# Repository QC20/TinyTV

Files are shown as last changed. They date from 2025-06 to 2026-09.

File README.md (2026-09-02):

# TinyTV

A small 3D-printed television with a Raspberry Pi inside. It plays a library of
episodes and old commercials on a loop — no menu, no remote, no interface. You
flip the switch on the side and something is on, the way a TV in the corner of a
room used to work.

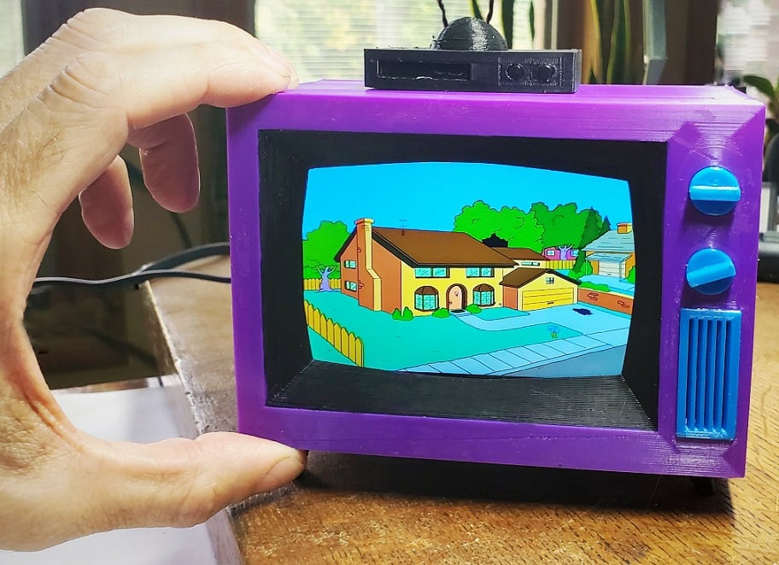
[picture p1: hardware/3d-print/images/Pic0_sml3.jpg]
The printed enclosure


*Enclosure model and photo by [highping on Thingiverse](https://www.thingiverse.com/thing:5019648), used under CC BY.*

The Pi boots straight into a video player. There is no desktop and nothing to log
into. Episodes are shuffled, and after each one a commercial plays before the
next episode starts — which is most of what makes it feel like television rather
than a video player in a box.

## How it works

Everything is pre-processed on a desktop machine, so the Pi only ever has to do
the easy job of playing files. Videos are encoded down to roughly 780×480 and
rotated to match the panel, black bars cropped, subtitles burned in if there are
any. That happens once, in [code/encoding](code/encoding).

On the Pi, [player.py](code/player/player.py) shuffles the contents of
`videos/tv` and `videos/commercials`, then alternates between them forever. It
plays through `mpv` on the DRM video output, which draws directly to HDMI with no
X server running. Before each file it probes the codec with `ffprobe` and picks
its decoder flags accordingly: H.264 goes to the Pi's hardware decoder, anything
else (H.265, VP9, AV1) falls back to software with the loop filter switched off,
because a Pi 3B has no hardware path for those and will otherwise drop most of
the frames.

Play counts are written to `playback_state.txt` next to the script — a plain text
file you can open and read, on purpose.

[buttons.py](code/player/buttons.py) watches a toggle switch on GPIO 26. When
it's off, GPIO 18 goes low to kill the backlight and GPIO 19 is dropped back to
an input, which cuts the PWM audio feeding the amp. Screen and sound go together,
so the switch on the side of the case behaves like a real power switch.

## Hardware

| Part | Notes |
| --- | --- |
| Raspberry Pi 3B | The player is tuned for its decoder; a newer Pi has more headroom |
| Waveshare 4″ HDMI LCD | 800×480 IPS, resistive touch (unused here), HDMI + USB |
| Waveshare UPS HAT (D) | 2× 5300 mAh cells, INA219 current sensor on I²C `0x43` |
| Adafruit MAX98357 | Class-D mono amp driving a small speaker |
| Toggle switch, 1 kΩ pot, relay | Power and volume on the front panel |

Wiring diagram (again from the original build):
[hardware/3d-print/images/Wiring.jpg](hardware/3d-print/images/Wiring.jpg).
Datasheets for the HAT and the amp are in [hardware/datasheets](hardware/datasheets).

## Layout

```text
boot/          Files that go on the SD card's boot partition before first boot
code/
  player/      What runs on the Pi: playback loop and the power switch handler
  encoding/    Desktop-side ffmpeg tooling that prepares videos for the screen
  monitoring/  Battery, temperature and system telemetry over the INA219
  video-analysis/  Library statistics — how many hours of content is on there
  experiments/ Parked attempts, kept for reference
docs/          Display setup guide and the playback design notes
hardware/      STLs, Fusion 360 source, renders and component datasheets
samples/       An example encoded clip
```

## Getting one running

1. Flash Raspberry Pi OS Lite and set the Pi up headless. The display needs a
   custom HDMI mode and a device tree overlay before it will show anything —
   [docs/pi-display-setup.md](docs/pi-display-setup.md) has the exact
   `config.txt` lines and the touchscreen overlay.
2. Copy the contents of [boot/](boot/) to the boot partition. Fill in your own
   SSID and password in `wpa_supplicant.conf` first.
3. Install the runtime dependencies on the Pi:
   ```bash
   sudo apt install mpv ffmpeg python3-rpi.gpio
   pip3 install pi-ina219 psutil
   ```
4. Encode your videos with [code/encoding/480x800-screen.py](code/encoding/480x800-screen.py)
   and copy them to `code/player/videos/tv` and `code/player/videos/commercials`.
5. Run `python3 player.py`. Once it looks right, put it behind a systemd unit so
   it comes up on boot.

## Known gaps

This is a finished object rather than a finished piece of software, and a few
things never got past "good enough":

- **Playback state only saves on a clean exit.** `player.py` writes
  `playback_state.txt` when you Ctrl+C it. Pull the power — which is how the
  thing is normally switched off — and the session's play counts are lost.
- **The rotation is a shuffle, not the design in the notes.**
  [docs/playback-design.md](docs/playback-design.md) describes a session system
  that picks randomly from what hasn't played yet, survives restarts, and picks
  up new files automatically. `code/experiments/player_WITH-CIRCULATION.py`
  implements it, but it plays through `--hwdec=auto` and stutters badly on a
  3B, so the simpler shuffle is what actually ships.
- **The VCR buttons aren't wired to anything.** The case models two micro
  switches into the VCR on top. Skip and rewind would be the obvious use.
- **No service file.** Starting on boot is left to you.

## Credits

The enclosure is [The Simpsons TV (Remixed for HDMI display)](https://www.thingiverse.com/thing:5019648)
by **highping**, itself a remodel of [buba447's original](https://www.thingiverse.com/thing:4943159).
buba447's [build guide](https://withrow.io/simpsons-tv-build-guide) still covers
most of the hardware side; the display setup is the part that differs.

## License

The code in this repository is MIT licensed — see [LICENSE](LICENSE).

The 3D models in [hardware/3d-print](hardware/3d-print) are not mine and are not
covered by that. They are Creative Commons Attribution, by highping — see
[hardware/3d-print/LICENSE.txt](hardware/3d-print/LICENSE.txt).

Bring your own video. Nothing here ships with content, and the point is to play
things you already own.

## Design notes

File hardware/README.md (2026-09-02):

# Hardware

**`3d-print/`** — the enclosure. STLs in `stl/`, the Fusion 360 source as
`Simpsons_TV.f3d`, and renders and build photos in `images/`. `THINGIVERSE.txt`
is the original author's description, including print orientations and the
wiring notes worth reading before you start.

Print the front face down (the grill is a separate part so it needs no support).
The VCR and the volume knob are the only pieces that want support.

This is not my model — it's [The Simpsons TV (Remixed for HDMI display)](https://www.thingiverse.com/thing:5019648)
by highping, CC BY. See `LICENSE.txt`.

**`datasheets/`** — vendor documentation for the two boards that needed it:
the Waveshare UPS HAT (D) and the Adafruit MAX98357 I²S amp.

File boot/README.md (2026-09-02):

# Boot partition files

Copy these to the root of the SD card's `boot` partition before the Pi's first
boot. They are read once at startup and then ignored.

| File | Purpose |
| --- | --- |
| `wpa_supplicant.conf` | Wi-Fi credentials. **Fill in your own SSID and password** — the committed values are placeholders. |
| `ssh` | Empty file. Its presence enables the SSH server on first boot. |
| `waveshare-ads7846.dtbo` | Device tree overlay for the display's ADS7846 resistive touch controller. This one goes in `/boot/overlays/`, not the root. |

`config.txt` also needs the HDMI mode for the 800×480 panel — those lines are in
[../docs/pi-display-setup.md](../docs/pi-display-setup.md).

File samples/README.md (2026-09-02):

# Samples

`480x320.mp4` is an encoded clip, kept as a reference for what the converter
output looks like — resolution, bitrate and how it sits on the panel.

It is 480×320, from an earlier build that used a smaller screen. The current
target is 780×480; see [../code/encoding](../code/encoding).

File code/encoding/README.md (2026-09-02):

# Encoding videos for the screen

The Pi is not fast enough to scale and decode arbitrary video in real time, so
everything gets converted once on a desktop machine and copied over ready to
play. These are the ffmpeg wrappers that do it.

`480x800-screen.py` is the one to use. The others are kept in `deprecated/`
because earlier builds used different panels.

## What it does

Per file, in this order:

1. **Crops black bars.** Samples the frame at 10%, 50% and 90% through the video
   and crops letterboxing when it exceeds 2% of the frame. Sampling at three
   points avoids being fooled by a dark opening shot.
2. **Picks target dimensions.** Height is fixed at 480. Width is allowed to land
   anywhere between 770 and 800, preferring 780 — the case covers a few pixels
   at the edges, so filling the panel exactly wastes them. It searches for the
   width that needs the least stretching, staying inside a 12% stretch / 20%
   squeeze limit.
3. **Burns in subtitles** if a `.srt` with the same base name sits next to the
   source. 18px Arial with a 2px outline, which is about the smallest that stays
   readable on a 4″ panel.
4. **Rotates 90°** if `ROTATE` is on, subtitles along with it.
5. **Encodes** to H.264 Main / Level 3.0, CRF 23, `veryslow`, AAC audio at
   256 kbps, `yuv420p`, faststart.

Existing outputs are skipped, and sources are never modified.

## Requirements

ffmpeg on PATH, and Python 3.

```bash
sudo apt install ffmpeg    # Debian/Raspberry Pi OS
brew install ffmpeg        # macOS
```

## Use

Put your videos in an `input/` folder beside the script; `output/` is created
for you.

```text
code/encoding/
├── 480x800-screen.py
├── input/     <- source videos (and matching .srt files, if any)
└── output/    <- converted files land here
```

```bash
python3 480x800-screen.py
```

Progress looks like this:

```text
(1/10)
Analyzing 'sample_video'...
  Original dimensions: 1920x1080
  Duration: 00:05:23
  Found subtitle file: sample_video.srt
  Detecting black bars (sampling 10s)...
  Black bars detected! Original: 1920x1080, After crop: 1920x800
  Optimal target dimensions: 780x480
  Applying rotation: counterclockwise
Encoding 'sample_video' with filters: crop=1920:800:0:140,scale=780:480,...
  Progress: [====================] 100.00% (00:05:23 / 00:05:23)
 -> Done in 142.3s, size=8472 KB
```

Roughly 6–8 minutes per 30-minute episode on a modern laptop, scaling with how
many threads you give it.

## Settings

All near the top of the script:

```python
TARGET_HEIGHT = 480
TARGET_WIDTH_PREFERRED = 780
TARGET_WIDTH_MIN = 770
TARGET_WIDTH_MAX = 800

ROTATE = True
ROTATE_DIR = 'counterclockwise'

MAX_STRETCH = 1.12          # how much distortion to tolerate
MIN_SQUEEZE = 0.80

SUBTITLE_FONT_SIZE = 18
SUBTITLE_FONT_NAME = 'Arial'
SUBTITLE_OUTLINE = 2

MAX_CPU_THREADS = multiprocessing.cpu_count() // 2
```

Worth knowing:

- **Video looks stretched** — tighten `MAX_STRETCH` and `MIN_SQUEEZE` towards 1.0.
- **Too slow** — raise `MAX_CPU_THREADS`, or change the preset from `veryslow`
  to `medium`. `veryslow` buys maybe 5% file size for several times the wait.
- **Rotated the wrong way** — flip `ROTATE_DIR`.
- **Quality** — CRF 18 is close to lossless and much larger, 23 is the default,
  26 is noticeably softer but small. On a 4″ screen 26 is more defensible than
  it sounds.

## The deprecated scripts

| Script | Target |
| --- | --- |
| `TinyTV_Converter.py` | Same as `480x800-screen.py`, but reads from `~/Desktop/c_input` instead of a folder beside the script |
| `video-converter_800x480.py` | Aspect-preserving 480p for a normal monitor |
| `video-converter_480x320.py` | Fixed 480×320 with letterboxing, for 2.8″–3.5″ panels |
| `800x480_Resolution.py` | Earlier pass at the 800×480 conversion |

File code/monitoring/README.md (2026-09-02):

# Monitoring

Diagnostics for the UPS HAT, run over SSH. None of this is needed for playback.

| Script | What it shows |
| --- | --- |
| `battery-monitor.py` | One reading: voltage, current, power, shunt voltage |
| `battery_watch.py` | The same on a 3-second loop, plus charge state and a runtime estimate |
| `status.py` | Full dashboard — battery, CPU load and temperature, GPU clock, RAM, disk, network throughput, top processes, and firmware throttle flags |

All three talk to the INA219 on the UPS HAT at I²C address `0x43`, with a 0.1 Ω
shunt. Capacity is hardcoded to 10600 mAh (2× 5300 mAh); change
`BATTERY_CAPACITY_MAH` if your pack differs.

Battery percentage is interpolated from voltage between 3.0 V and 4.2 V. That's
a rough approximation — lithium cells sit near 3.7 V for most of their discharge,
so the middle of the range reads low and the number moves in jumps.

```bash
pip3 install pi-ina219 psutil
python3 status.py
```

I²C needs to be enabled (`raspi-config` → Interface Options → I2C).

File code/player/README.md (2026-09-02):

# Player

What runs on the Pi.

**`player.py`** shuffles `videos/tv` and `videos/commercials` (both relative to
this file) and alternates between them: an episode, then a commercial, then the
next episode. Playback goes through `mpv --vo=drm` straight to HDMI, so no
desktop is needed.

Decoder flags are chosen per file after probing the codec with `ffprobe`. H.264
uses the Pi's hardware decoder; H.265, VP9 and AV1 fall back to four software
threads with the loop filter disabled, which is the difference between watchable
and a slideshow on a 3B. Encode to H.264 and none of this matters.

Play counts go to `playback_state.txt` next to the script, written on Ctrl+C.

```bash
mkdir -p videos/tv videos/commercials
# copy encoded files in, then
python3 player.py
```

**`buttons.py`** polls a toggle switch on GPIO 26 every 300 ms. On, it drives
GPIO 18 high for the backlight and puts GPIO 19 into ALT5 — its PWM audio
function — via `raspi-gpio`. Off, it reverses both, so screen and sound come up
and go down together.

If yours works backwards, invert the read; there's a comment in the loop marking
the line.

Needs `mpv`, `ffmpeg` and `RPi.GPIO`.

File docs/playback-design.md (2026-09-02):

# Playback rotation — design notes

What the video counter system was meant to do. This is the spec, not a
description of what ships; see [Known gaps](../README.md#known-gaps) for where
the two diverge.

## Session-based cycle

A *session* is one pass in which every video file plays exactly once. When
everything has played, a new session starts. Sessions repeat indefinitely.

## Random, but constrained

Pick randomly, but only from the videos that haven't played yet this session.
Straight random selection means an unlucky file can go months without coming up;
drawing without replacement spreads playtime evenly while keeping the order
unpredictable.

## State survives restarts

If the player stops, it resumes where it left off. Videos already played this
session stay marked as played, and the rest stay in the pool.

## History is kept

Track total plays per file across all sessions, not just the current one. A new
session resets the "played this session" flag but not the running count, so
"this one has been on 47 times" stays true.

## New files are picked up on their own

Anything dropped into the video directories is detected and joins the current
session as unplayed. Nothing to register by hand.

## The tracking file is readable

`playback_state.txt` is plain text so anyone can open it and see what has played,
what hasn't, and how often — no database, no JSON.

---

In short: fair rotation that remembers where it was, keeps its history, and
stays legible to someone who doesn't write code.

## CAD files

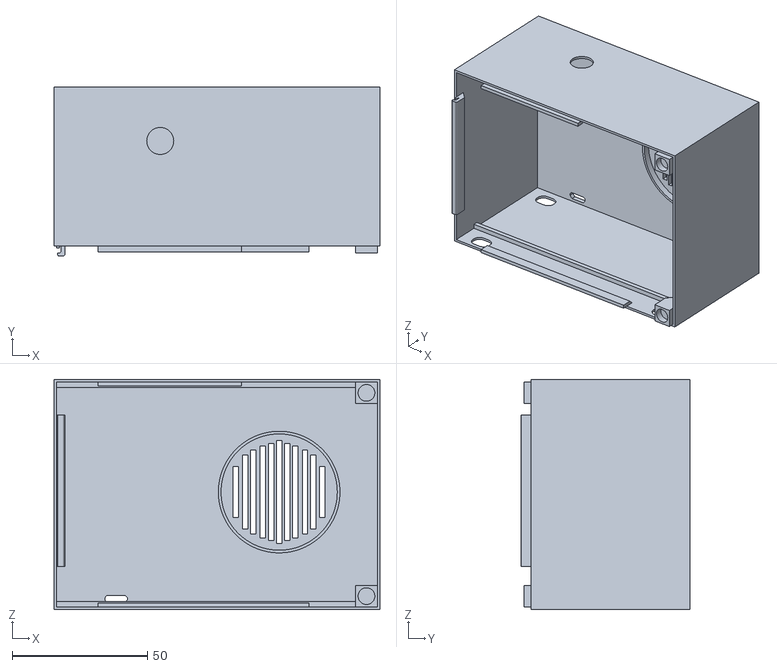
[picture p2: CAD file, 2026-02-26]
hardware/3d-print/stl/STV_Body.stl
120.6 x 62.6 x 85.2

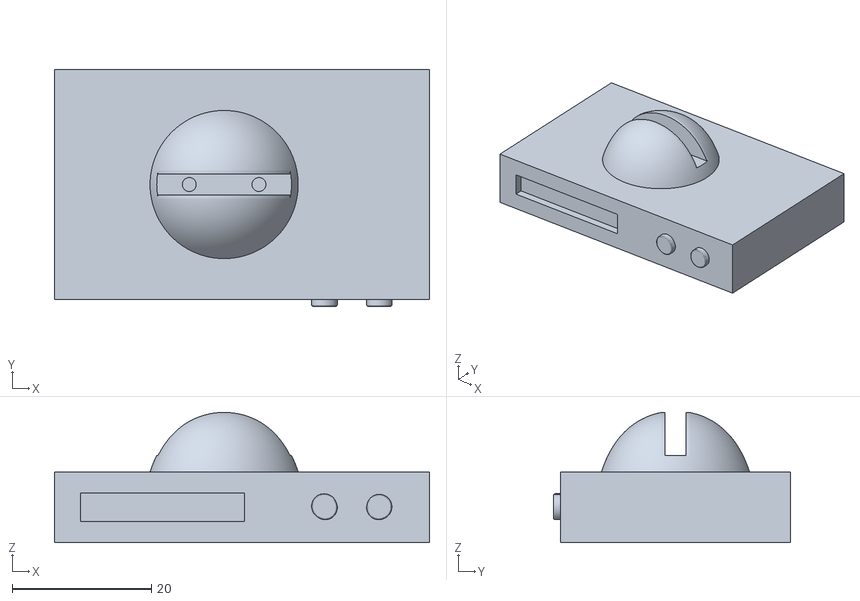
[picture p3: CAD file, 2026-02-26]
hardware/3d-print/stl/STVmod_VCR_solid_buttons.stl
53.8 x 34.0 x 18.7

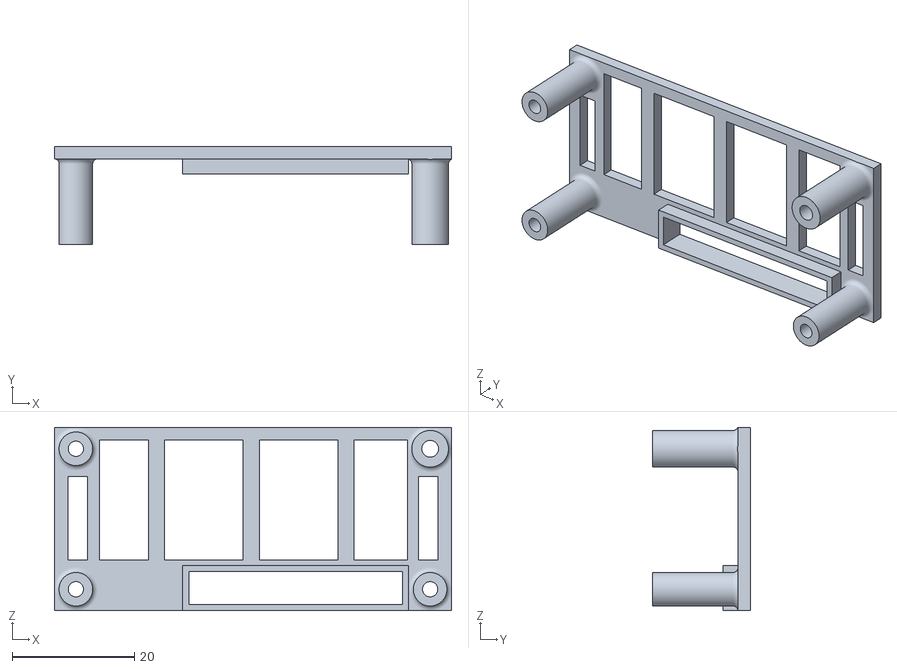
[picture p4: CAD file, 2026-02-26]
hardware/3d-print/stl/standoff.stl
65.0 x 16.0 x 30.0

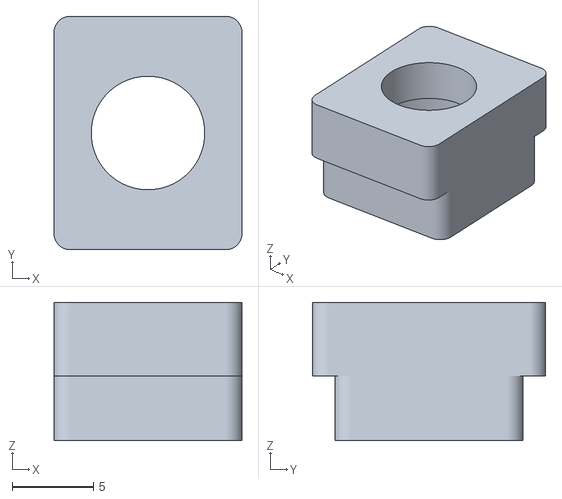
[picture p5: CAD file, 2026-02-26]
hardware/3d-print/stl/STV_Vknob_Base.stl
11.6 x 14.4 x 8.53

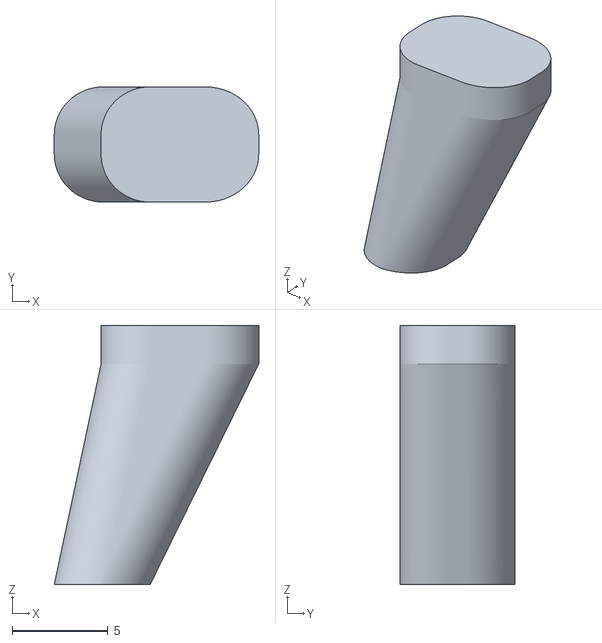
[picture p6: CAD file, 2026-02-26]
hardware/3d-print/stl/STV_Leg.stl
10.7 x 6.00 x 13.5

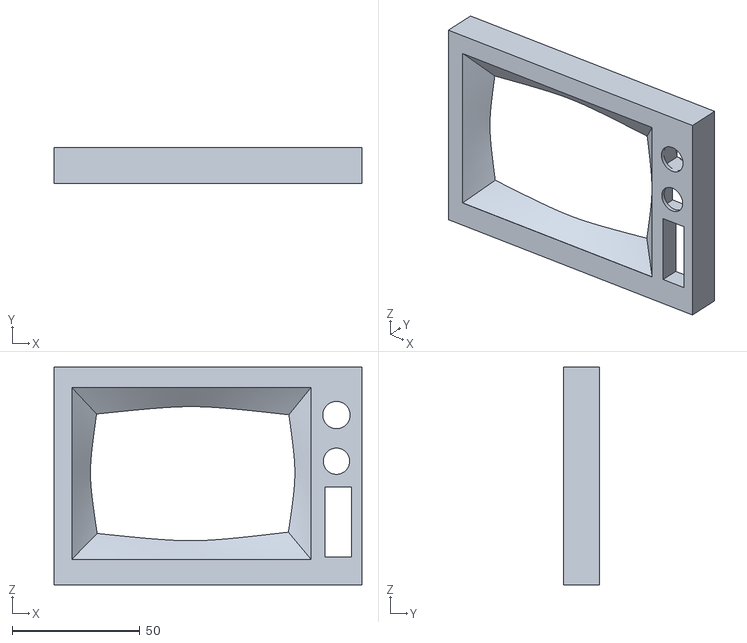
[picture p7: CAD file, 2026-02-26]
hardware/3d-print/stl/STV_Front.stl
120.6 x 14.0 x 85.2

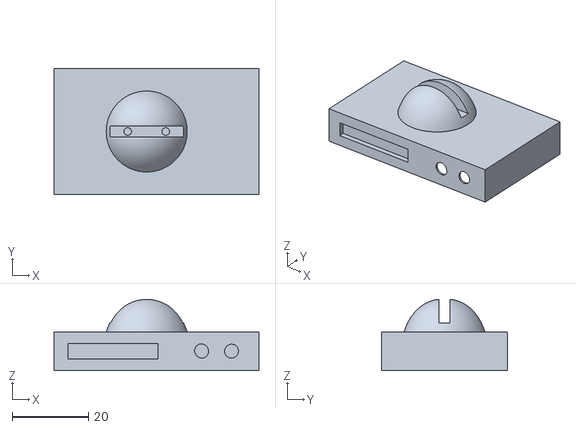
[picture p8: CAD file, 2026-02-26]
hardware/3d-print/stl/STV_VCR.stl
53.8 x 33.0 x 18.7

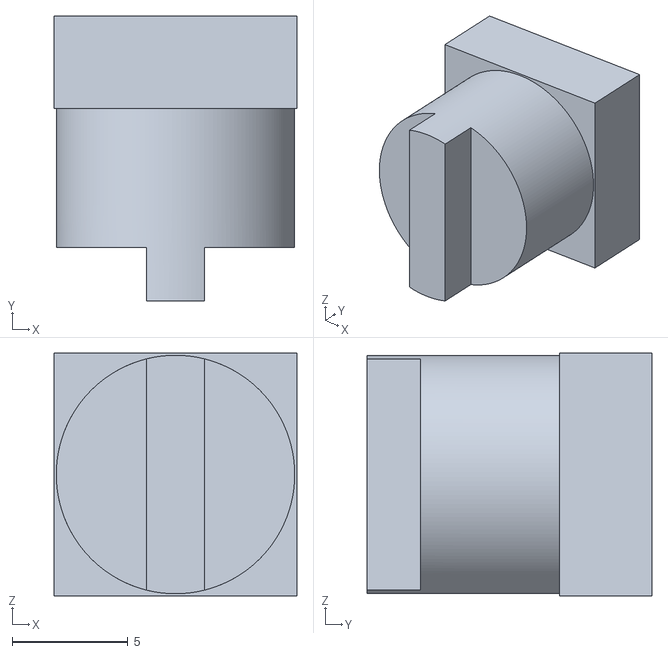
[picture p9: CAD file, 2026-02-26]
hardware/3d-print/stl/STV_Pknob.stl
10.5 x 12.3 x 10.5

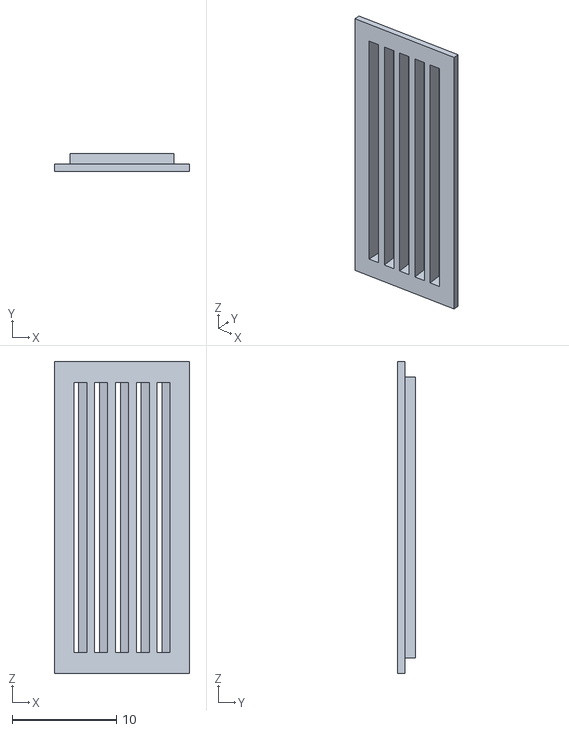
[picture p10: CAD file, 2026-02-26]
hardware/3d-print/stl/STV_Front_insert.stl
13.0 x 1.70 x 30.0

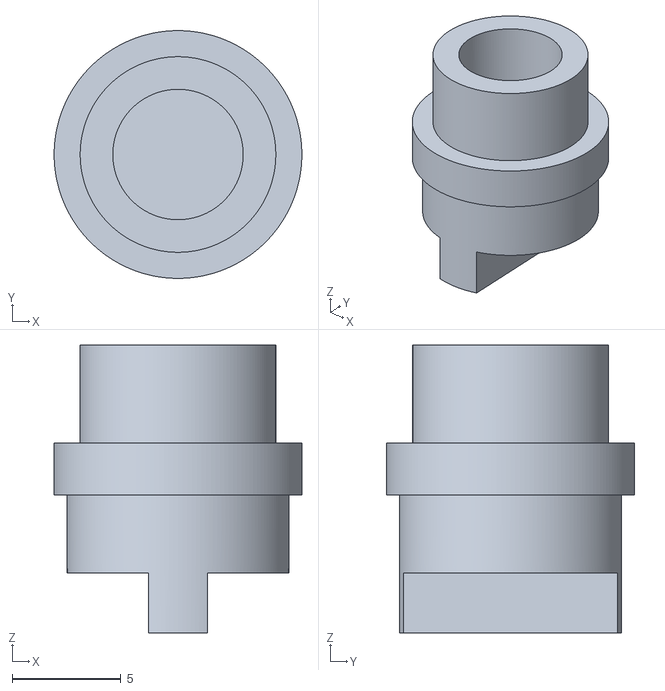
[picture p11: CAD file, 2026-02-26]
hardware/3d-print/stl/STV_VKnob.stl
11.4 x 11.4 x 13.2

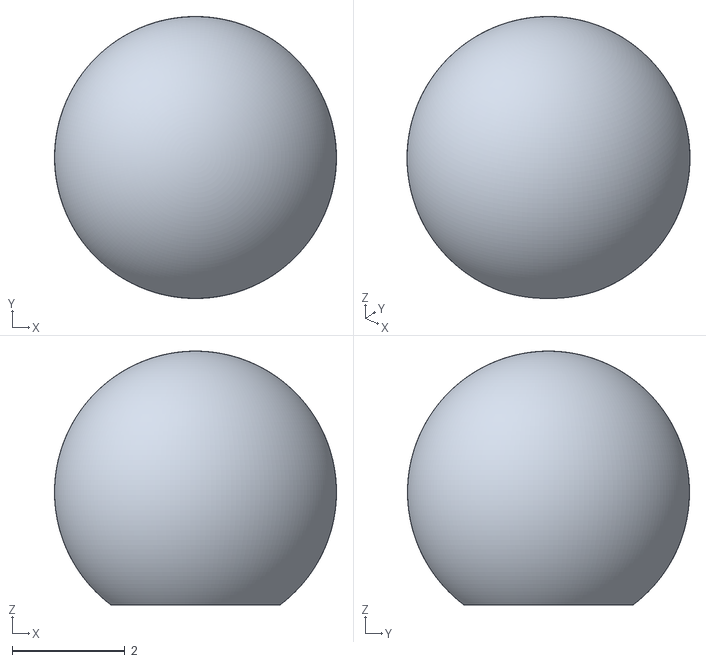
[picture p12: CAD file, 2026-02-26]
hardware/3d-print/stl/STV_AntennaTop.stl
5.00 x 5.00 x 4.50

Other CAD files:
hardware/3d-print/stl/STVmod_Body_no_hole_on_top.stl
hardware/3d-print/Simpsons_TV.f3d

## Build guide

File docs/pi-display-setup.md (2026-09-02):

# Setting up the Waveshare 4" HDMI LCD

Getting a Waveshare 4-inch HDMI LCD (800×480) working on a headless Raspberry
Pi: Wi-Fi and SSH, the HDMI mode the panel needs, and the touchscreen overlay.
The display will not show anything until `config.txt` is right, so this has to
happen before the Pi is any use.

Ready-made copies of the files mentioned here are in [../boot](../boot).

---

## Prerequisites

- **Raspberry Pi** (any model with HDMI output)
- **microSD card** (≥8 GB)
- **Waveshare 4″ HDMI LCD (800×480)**
- **micro USB power supply** (≥2 A recommended)
- **A computer** (Windows/macOS/Linux) with:
  - SD-card reader
  - Text editor (e.g., Sublime, VS Code, Notepad++)

---

## 1. Download & Flash Raspberry Pi OS

1. Download the latest Raspberry Pi OS image from the official Raspberry Pi website:
   - https://www.raspberrypi.com/software/ (choose “Raspberry Pi OS Lite” for a headless setup)

2. Flash the image to your microSD card using **Raspberry Pi Imager** or **BalenaEtcher**:
   - Raspberry Pi Imager: https://www.raspberrypi.com/software/
   - BalenaEtcher: https://www.balena.io/etcher/

3. Once flashing completes, eject and re-insert the microSD card. It should mount on your computer as a drive named `boot`.

---

## 2. Headless Wi-Fi & SSH Setup

> These two steps let your Pi connect to Wi-Fi on first boot and enable SSH access.

1. **Create `wpa_supplicant.conf`**
   In your preferred text editor, paste:
   ```conf
   country=US
   ctrl_interface=DIR=/var/run/wpa_supplicant GROUP=netdev
   update_config=1

   network={
       ssid="YOUR_WIFI_SSID"
       psk="YOUR_WIFI_PASSWORD"
   }
   ```
   Replace `YOUR_WIFI_SSID` and `YOUR_WIFI_PASSWORD` exactly (case-sensitive).

   Change `country=US` to your two-letter ISO country code if you’re not in the U.S. (e.g., GB, DE, DK).

   Save the file as `wpa_supplicant.conf` to the root of the `boot` partition (the same folder as `config.txt`).

2. **Create an empty `ssh` file** (no extension) in the root of the `boot` partition.

   On Windows: Right-click → New → Text Document → Rename to `ssh` (remove `.txt`).

   On macOS/Linux:
   ```bash
   touch /Volumes/boot/ssh
   ```
   This blank file tells Raspberry Pi OS to enable the SSH server on first boot.

---

## 3. Display Configuration (config.txt)

The Waveshare 4″ HDMI LCD requires a custom HDMI mode + optional touchscreen overlay. Edit the existing `config.txt` on the `boot` partition as follows:

1. Open `/boot/config.txt` in your text editor.

2. Scroll down to the bottom and add (or replace) these lines under the `[all]` section (create `[all]` if it isn’t already there):

   ```ini
   [all]
   # Use a custom HDMI mode for 800×480 @ 60 Hz
   hdmi_group=2
   hdmi_mode=87
   hdmi_cvt=800 480 60 6 0 0 0
   hdmi_drive=2

   # Rotate the display 90° clockwise (adjust if you want a different orientation)
   display_rotate=1

   # Enable GPIO 18 to control the backlight (Waveshare’s wiring)
   gpio=18=op,dh
   ```
   - `hdmi_group=2` + `hdmi_mode=87` + `hdmi_cvt` → forces Pi to output 800×480
   - `display_rotate=1` → rotates the screen upright (change to `2`/`3`/`0` as needed)
   - `gpio=18=op,dh` → configures GPIO 18 as an output and drives it HIGH at boot (powers the backlight)

3. Save and close `config.txt`.

---

## 4. Touchscreen Overlay (.dtbo)

If your particular Waveshare model includes a resistive touchscreen controller (ADS7846), add the Device Tree overlay so the touchscreen works.

1. **Get the `.dtbo` file.**
   A copy is in [../boot/waveshare-ads7846.dtbo](../boot/waveshare-ads7846.dtbo).
   The current version is on the official wiki under “Resources → Raspbian
   Driver”: https://www.waveshare.com/wiki/4inch_HDMI_LCD

2. **Copy `waveshare-ads7846.dtbo` into the Pi’s overlays folder:**
   Insert the SD card if it’s not already mounted.

   Copy `waveshare-ads7846.dtbo` to:
   ```bash
   /boot/overlays/
   ```

3. **Enable the overlay:**
   Edit `config.txt` again (the same file in `/boot/`), and add this line below your HDMI settings:

   ```ini
   dtoverlay=waveshare-ads7846,penirq=25,xmin=150,xmax=3900,ymin=100,ymax=3950,speed=50000
   ```
   This configures the ADS7846 touchscreen on GPIO 25 (`PENIRQ`) and calibrates X/Y ranges.

   Adjust `xmin`/`xmax`/`ymin`/`ymax` if you need further calibration.

4. Save/close `config.txt`.

---

## 5. Final Steps & Boot

1. Eject the microSD card safely from your computer.
2. Insert it into your Raspberry Pi.
3. Connect the HDMI cable from Pi → Waveshare LCD Screen.
4. Connect your micro USB power (≥2 A).
5. Alternatively, you can control power source through a [power HAT](https://www.waveshare.com/catalog/product/view/id/3844/s/li-polymer-battery-hat/category/37/) (like I have done in this build).

The LCD’s backlight should turn on automatically. You should see boot text on the screen (e.g., kernel messages).

**SSH into your Pi** (if Wi-Fi is configured):

```bash
ssh pi@<YOUR_PI_IP_ADDRESS>
# Default password: raspberry
```
If you’re unsure of the Pi’s IP, attach an HDMI monitor or check your router’s DHCP list.

---

## 6. Verify & Troubleshoot

**No image on LCD:**
- Double-check that `hdmi_cvt=800 480 60 6 0 0 0` is correct and under `[all]`.
- Make sure `hdmi_drive=2` is present (enables HDMI sound/backlight).
- Verify `gpio=18=op,dh` if backlight stays off.
- Try a different HDMI cable or port.

**Touchscreen not responding:**
- Ensure `waveshare-ads7846.dtbo` is in `/boot/overlays/`.
- Confirm `dtoverlay=waveshare-ads7846,...` is at the bottom of `config.txt`.
- Check GPIO 25 (“PENIRQ”) wiring.
- For further calibration, see Waveshare’s ADS7846 documentation:
  https://www.waveshare.com/wiki/4inch_HDMI_LCD

**Headless/Wi-Fi issues:**
- Make sure `wpa_supplicant.conf` is in `/boot/`.
- Confirm SSID/PSK are correct (case-sensitive).
- Reboot Pi, then check router’s DHCP table for the Pi’s IP.

---

## Reference Links

- **Waveshare 4″ HDMI LCD Wiki** (official driver & .dtbo downloads):
  https://www.waveshare.com/wiki/4inch_HDMI_LCD

- **Raspberry Pi OS Download & Imager**:
  https://www.raspberrypi.com/software/

- **Headless SSH & Wi-Fi Setup Guide** (Raspberry Pi Foundation):
  https://www.raspberrypi.com/documentation/computers/configuration.html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

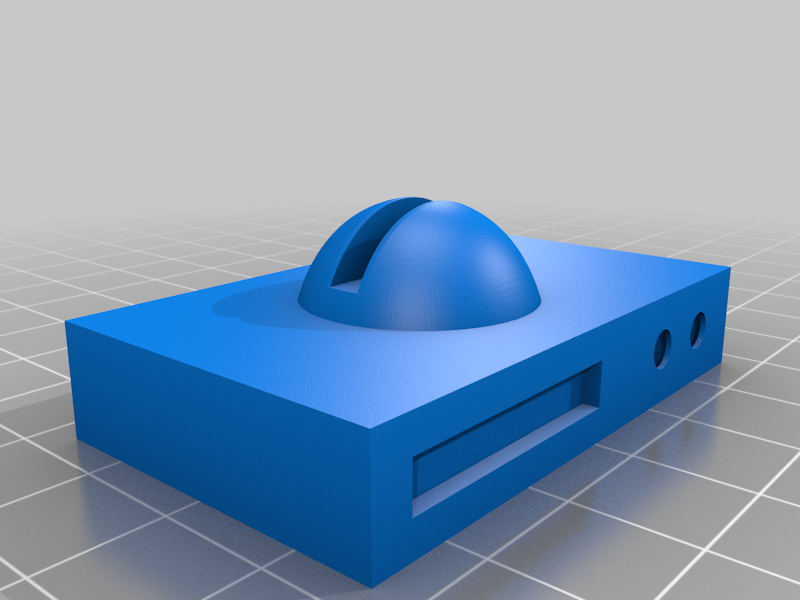
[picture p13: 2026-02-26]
hardware/3d-print/images/STV_VCR.png

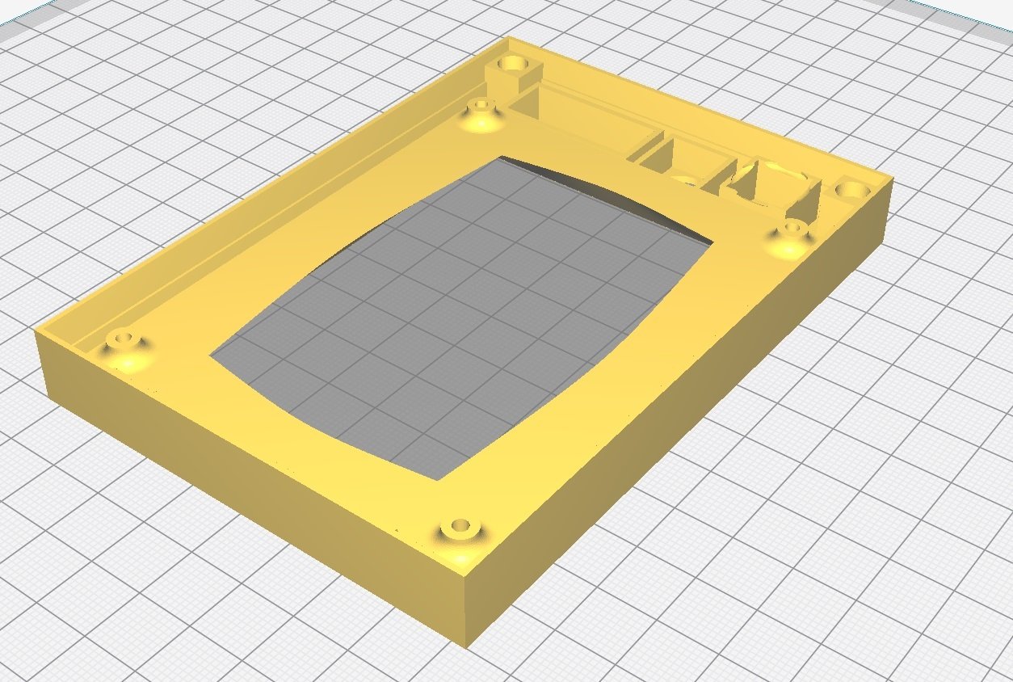
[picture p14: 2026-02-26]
hardware/3d-print/images/STV_Frontpurple.jpg

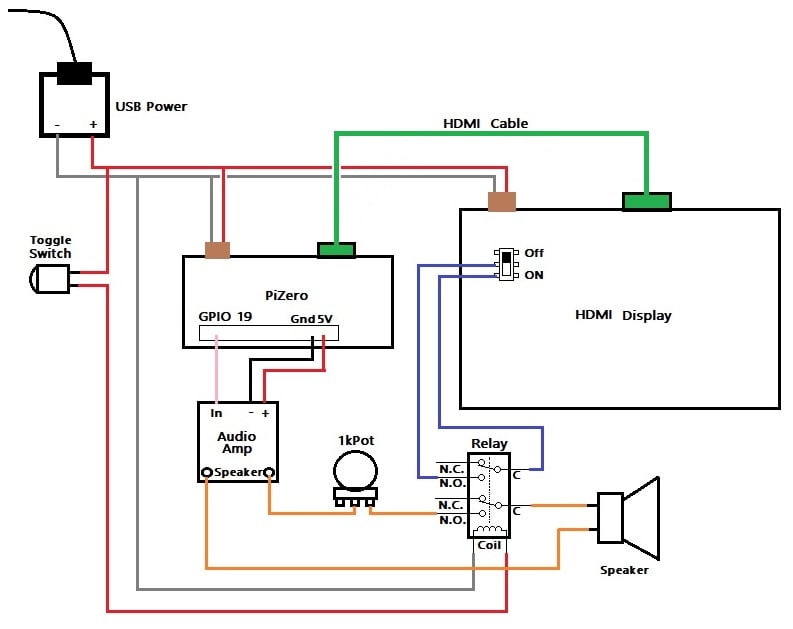
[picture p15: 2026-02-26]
hardware/3d-print/images/Wiring.jpg

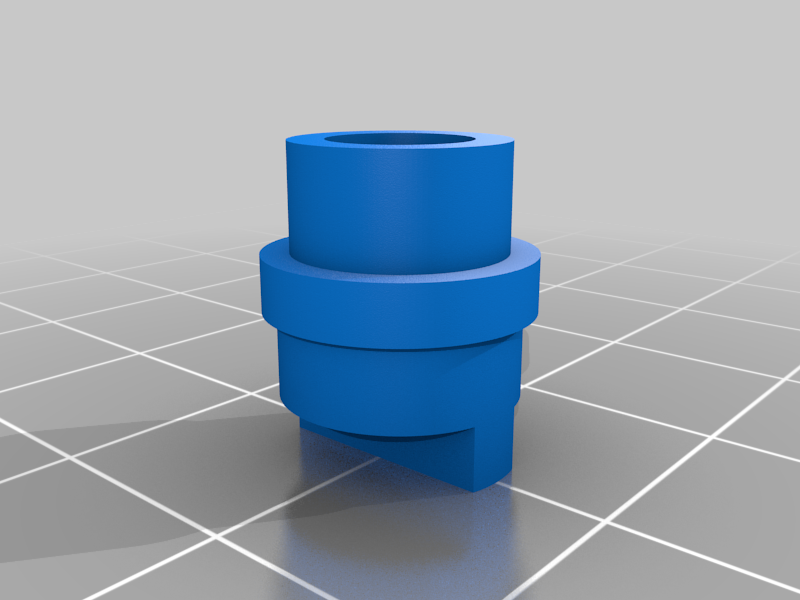
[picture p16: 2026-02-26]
hardware/3d-print/images/STV_VKnob.png

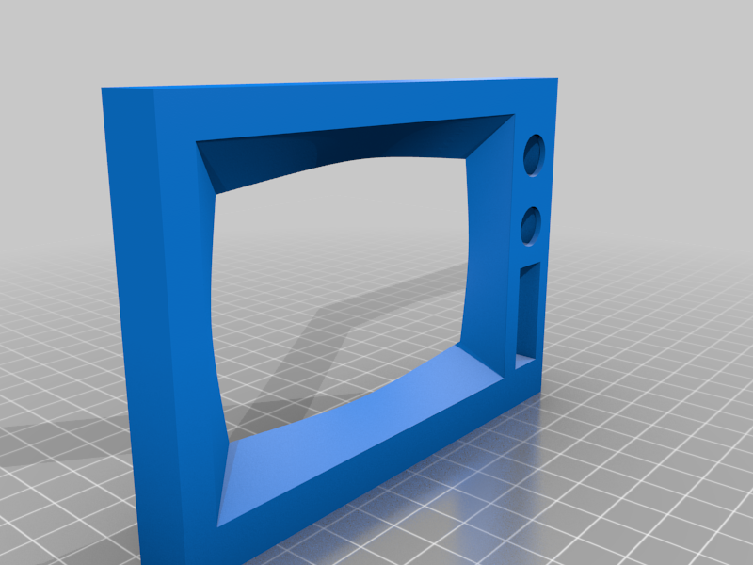
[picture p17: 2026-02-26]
hardware/3d-print/images/STV_Front.png

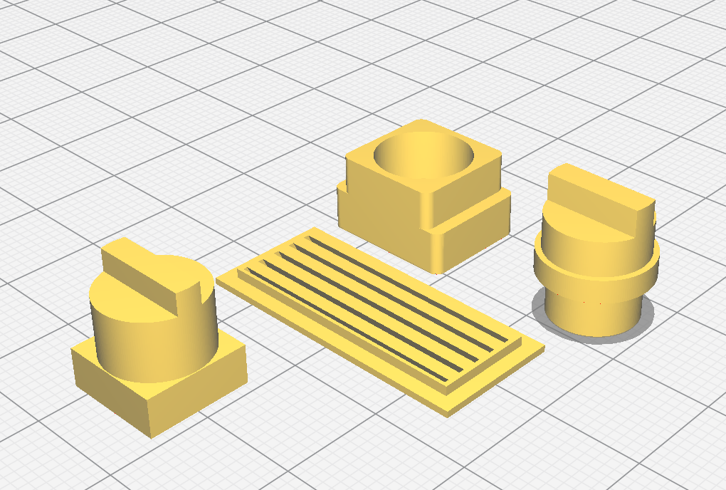
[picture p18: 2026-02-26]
hardware/3d-print/images/STV_knobs_and_plate_blue.png

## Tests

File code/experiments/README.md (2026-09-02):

# Experiments

Things that were tried and parked. Not wired into the build.

**`player_WITH-CIRCULATION.py`** implements the rotation described in
[../../docs/playback-design.md](../../docs/playback-design.md): a session picks
randomly from what hasn't played yet, state is saved after every file so a power
cut doesn't lose it, and files added or removed from the directories are picked
up on the next loop. Functionally it is what the player should do.

It plays through `--hwdec=auto` and calls `mpv` under `sudo`, and on a Pi 3B that
stutters badly on anything that isn't H.264. Merging its rotation logic into
`player.py`'s per-codec decoder selection is the obvious next step; nobody has
done it.

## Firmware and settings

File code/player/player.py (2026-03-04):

#!/usr/bin/env python3

import os
import sys
import random
import subprocess
from subprocess import Popen
from datetime import datetime

base_directory = os.path.join(os.path.dirname(os.path.realpath(__file__)), 'videos')
tv_directory = os.path.join(base_directory, 'tv')
commercials_directory = os.path.join(base_directory, 'commercials')
state_file = os.path.join(os.path.dirname(os.path.realpath(__file__)), 'playback_state.txt')

playback_state = {
    'session': 1,
    'tv': {},
    'commercials': {}
}

def loadPlaybackState():
    global playback_state
    if not os.path.exists(state_file):
        return
    try:
        with open(state_file, 'r', encoding='utf-8') as f:
            lines = f.readlines()
        current_category = None
        for line in lines:
            line = line.strip()
            if line.startswith('Current Session:'):
                playback_state['session'] = int(line.split(':')[1].strip())
            elif line == '--- TV SHOWS ---':
                current_category = 'tv'
            elif line == '--- COMMERCIALS ---':
                current_category = 'commercials'
            elif current_category and line.startswith('['):
                parts = line.split(' - ')
                if len(parts) >= 2:
                    played_this_session = '^|^s' in parts[0]
                    filename = parts[0].split(']')[-1].strip()
                    total_plays = int(parts[1].split(':')[1].strip()) if len(parts) > 1 else 0
                    last_played = parts[2].split(': ', 1)[1].strip() if len(parts) > 2 else 'never'
                    playback_state[current_category][filename] = {
                        'played_this_session': played_this_session,
                        'total_plays': total_plays,
                        'last_played': last_played
                    }
        print(f"Loaded playback state from session {playback_state['session']}")
    except Exception as e:
        print(f"Error loading playback state: {e}")

def savePlaybackState():
    try:
        with open(state_file, 'w', encoding='utf-8') as f:
            f.write("=== TinyTV Playback Tracker ===\n")
            f.write(f"Current Session: {playback_state['session']}\n")
            f.write(f"Started: {datetime.now().strftime('%Y-%m-%d')}\n\n")
            f.write("--- TV SHOWS ---\n")
            for filename, data in sorted(playback_state['tv'].items()):
                flag = "^|^s" if data.get('played_this_session') else " "
                f.write(f"[ {flag} ] {filename} - Total plays: {data.get('total_plays', 0)} - Last: {data.get('last_played', 'never')}\n")
            f.write("\n--- COMMERCIALS ---\n")
            for filename, data in sorted(playback_state['commercials'].items()):
                flag = "^|^s" if data.get('played_this_session') else " "
                f.write(f"[ {flag} ] {filename} - Total plays: {data.get('total_plays', 0)} - Last: {data.get('last_played', 'never')}\n")
    except Exception as e:
        print(f"Error saving playback state: {e}")

def get_video_codec(filepath):
    try:
        result = subprocess.run(
            ['ffprobe', '-v', 'quiet', '-select_streams', 'v:0',
             '-show_entries', 'stream=codec_name',
             '-of', 'default=noprint_wrappers=1:nokey=1', filepath],
            capture_output=True, text=True, timeout=5
        )
        return result.stdout.strip().lower()
    except Exception:
        return 'unknown'

def play_video(filepath):
    print(f"Playing: {filepath}")
    codec = get_video_codec(filepath)
    print(f"  Codec: {codec}")

    # Core arguments for DRM (HDMI output without a desktop)
    base_args = [
        'mpv', 
        '--vo=drm', 
        '--drm-connector=HDMI-A-1', 
        '--no-osd-bar', 
        '--really-quiet',
        '--cursor-autohide=always' # Keeps the mouse cursor hidden
    ]

    if codec in ('h264', 'avc'):
        # PRO TIP: Explicitly use the Pi's hardware decoder
        # 'v4l2m2m-copy' is the standard for modern Pi OS (Bullseye/Bookworm)
        # If this fails, try 'mmal'
        extra = [
            '--hwdec=v4l2m2m-copy', 
            '--cache=yes', 
            '--demuxer-max-bytes=30M', 
            '--video-sync=display-resample', # Smoother motion than audio-sync
            '--hr-seek=yes'
        ]
    elif codec in ('hevc', 'h265', 'vp9', 'av1'):
        # Pi 3B HAS no hardware for these. We must use CPU.
        # We lower the quality slightly to help the poor CPU keep up.
        extra = [
            '--hwdec=no', 
            '--vd-lavc-threads=4', 
            '--cache=yes', 
            '--demuxer-max-bytes=15M', 
            '--vd-lavc-fast',          # Skips some processing to gain speed
            '--vd-lavc-skiploopfilter=all' # Drastically reduces CPU load for H265
        ]
    else:
        extra = ['--hwdec=auto', '--cache=yes', '--video-sync=audio']

    process = Popen(base_args + extra + [filepath])
    process.wait()

def get_video_files(folder):
    return [f for f in os.listdir(folder) if f.lower().endswith((".mp4", ".mkv", ".avi", ".mov"))]

def mark_played(category, filename):
    now = datetime.now().strftime('%Y-%m-%d %H:%M')
    entry = playback_state[category].get(filename, {
        'played_this_session': False,
        'total_plays': 0,
        'last_played': 'never'
    })
    entry['played_this_session'] = True
    entry['total_plays'] += 1
    entry['last_played'] = now
    playback_state[category][filename] = entry

def playAlternatingVideos():
    tv_files = get_video_files(tv_directory)
    comm_files = get_video_files(commercials_directory)
    random.shuffle(tv_files)
    random.shuffle(comm_files)
    comm_index = 0
    for tv in tv_files:
        tv_path = os.path.join(tv_directory, tv)
        play_video(tv_path)
        mark_played('tv', tv)
        if comm_files:
            comm = comm_files[comm_index % len(comm_files)]
            comm_index += 1
            comm_path = os.path.join(commercials_directory, comm)
            play_video(comm_path)
            mark_played('commercials', comm)

def createDirectories():
    try:
        os.makedirs(tv_directory, exist_ok=True)
        os.makedirs(commercials_directory, exist_ok=True)
        return True
    except Exception as e:
        print(f"Directory creation failed: {e}")
        return False

def main():
    loadPlaybackState()
    tv_unplayed = sum(1 for d in playback_state['tv'].values() if not d.get('played_this_session', False))
    comm_unplayed = sum(1 for d in playback_state['commercials'].values() if not d.get('played_this_session', False))
    print(f"Remaining: {tv_unplayed} TV, {comm_unplayed} commercials")
    print("Press Ctrl+C to stop")
    try:
        playAlternatingVideos()
    except KeyboardInterrupt:
        print("Stopping TinyTV")
        savePlaybackState()
        sys.exit(0)

if __name__ == "__main__":
    if not createDirectories():
        sys.exit(1)
    main()

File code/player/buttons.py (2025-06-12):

#   This script is used to control the screen power state using a button connected to GPIO pins on a Raspberry Pi.
import RPi.GPIO as GPIO
import time
import os

# buttons.py
# Set up the GPIO pin for the button and screen control
# Ensure the raspi-gpio utility is installed and configured
os.system('raspi-gpio set 19 ip')
GPIO.setmode(GPIO.BCM)
GPIO.setup(26, GPIO.IN, pull_up_down=GPIO.PUD_UP)
GPIO.setup(18, GPIO.OUT)


# Function to turn on the screen by setting GPIO pin 19 to output and turning on GPIO pin 18
def turnOnScreen():
    os.system('raspi-gpio set 19 op a5')
    GPIO.output(18, GPIO.HIGH)


# Function to turn off the screen by setting GPIO pin 19 to input and turning off GPIO pin 18
def turnOffScreen():
    os.system('raspi-gpio set 19 ip')
    GPIO.output(18, GPIO.LOW)


# Initialize the screen state
turnOffScreen()
screen_on = False

# Main loop to check the button state and control the screen
while (True):
    # If you are having and issue with the button doing the opposite of what you want
    # IE Turns on when it should be off, change this line to:
    # input = not GPIO.input(26)
    input = GPIO.input(26)
    if input != screen_on:
        screen_on = input
        if screen_on:
            turnOnScreen()
        else:
            turnOffScreen()
    time.sleep(0.3)

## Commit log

2025-09-10 add print folder and files
2025-09-10 add print files to print folder (STL)
    [STV_AntennaTop.stl, STV_Body.stl, STV_Front.stl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]
2025-09-11 restructure repo
    [STV_AntennaTop.stl, STV_Body.stl, STV_Front.stl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]
2026-02-26 update repo
    [STV_AntennaTop.stl, STV_Body.stl, STV_Front.stl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]
2026-02-27 repo upgrade
    [STV_AntennaTop.stl, STV_Body.stl, STV_Front.stl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]
2026-02-27 add battery and overview scripts
2026-09-02 Restructure repo and rewrite the documentation
    The README was a Waveshare display setup guide with the project's name on
    top; it never said what TinyTV is. Moved that guide to docs/ and wrote a
    real README covering what the thing does, the hardware, how playback
    works, and what never got finished.
    Directory layout:
    - boot/ for the files that go on the SD card's boot partition
    - code/{player,encoding,monitoring,video-analysis,experiments}
    - hardware/{3d-print,datasheets}
    - docs/, samples/
    Dropped the apostrophe, ampersand and parentheses from directory names,
    fixed "deprecated-scipts" and "Wikishare", and flattened the Thingiverse
    bundle. Its README.txt is now THINGIVERSE.txt so it doesn't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
    [STV_AntennaTop.stl, STV_Body.stl, STV_Front.stl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]
